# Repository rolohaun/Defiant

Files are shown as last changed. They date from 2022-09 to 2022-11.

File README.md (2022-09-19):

# Defiant
 CroXY 3D Printer called Defiant
 
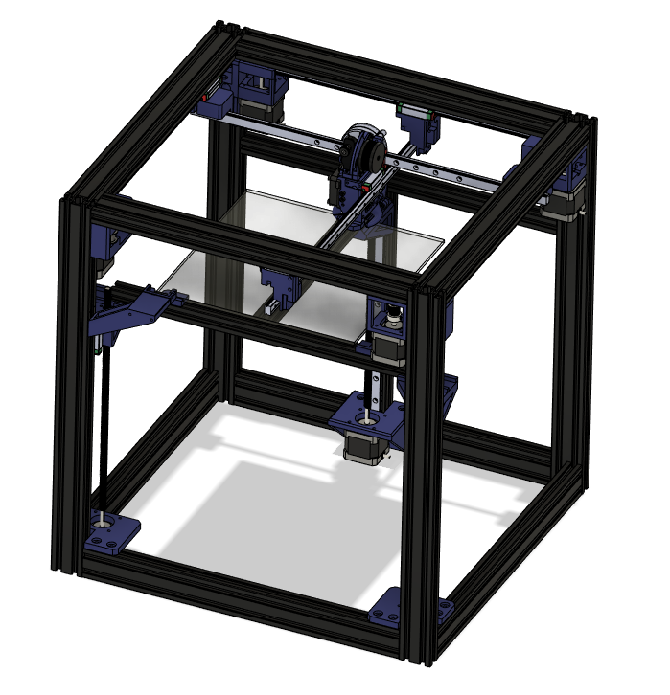
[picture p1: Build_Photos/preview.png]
 
 
 BETA Release
 This printer is a work in progress!! This printer is not enclosable in it's current form
 
 Specs:
 - 2040 Frame
 - 250 x 250 x 250 Printable Area
 - Klicky Probe Support
 - 3 Point Z tilt with independant Z motors
 
 BOM for Belted Z ( Work in Progress )  
 https://docs.google.com/spreadsheets/d/1MMBtSAIVklJtp9cDsU00cnw-aWT4j8f6p9V2ZHv14fQ/edit?usp=sharing
 
 BOM for Lead Screw Z ( Work in Progress )  
 https://docs.google.com/spreadsheets/d/1SVTLotEsgObyTigMcOwIdOpesXPSQrzdjuApPx5pESk/edit?usp=sharing
 
 Support me on Patreon  
 https://www.patreon.com/rolohaun
 
 Find it on YouTube

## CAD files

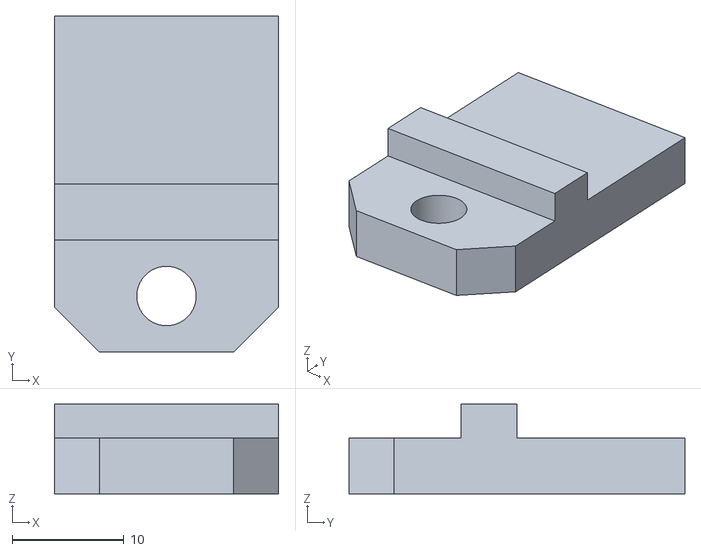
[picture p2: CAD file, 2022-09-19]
Bed/1 x Glass_Bed_Mount Rear.stl
20.0 x 30.0 x 8.00

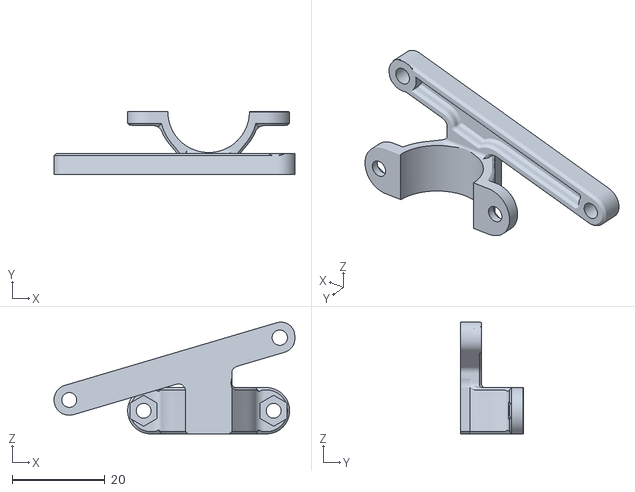
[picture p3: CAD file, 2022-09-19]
Cooling/Clamp_2.stl
52.1 x 13.5 x 24.2

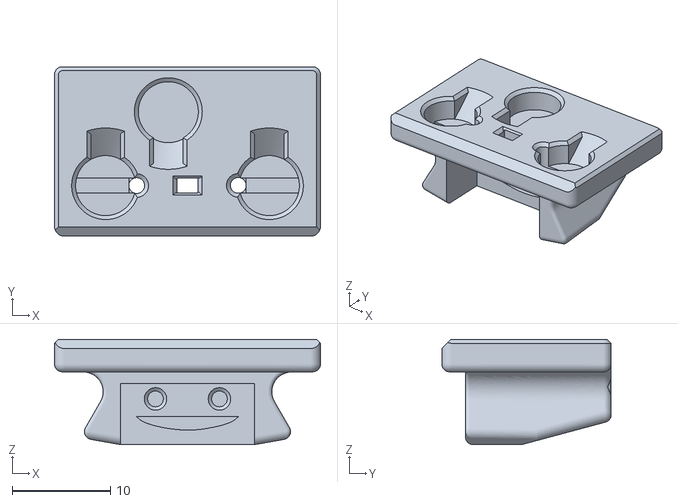
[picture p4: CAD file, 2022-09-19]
Klicky/Klicky_Probe.stl
27.0 x 17.2 x 10.7

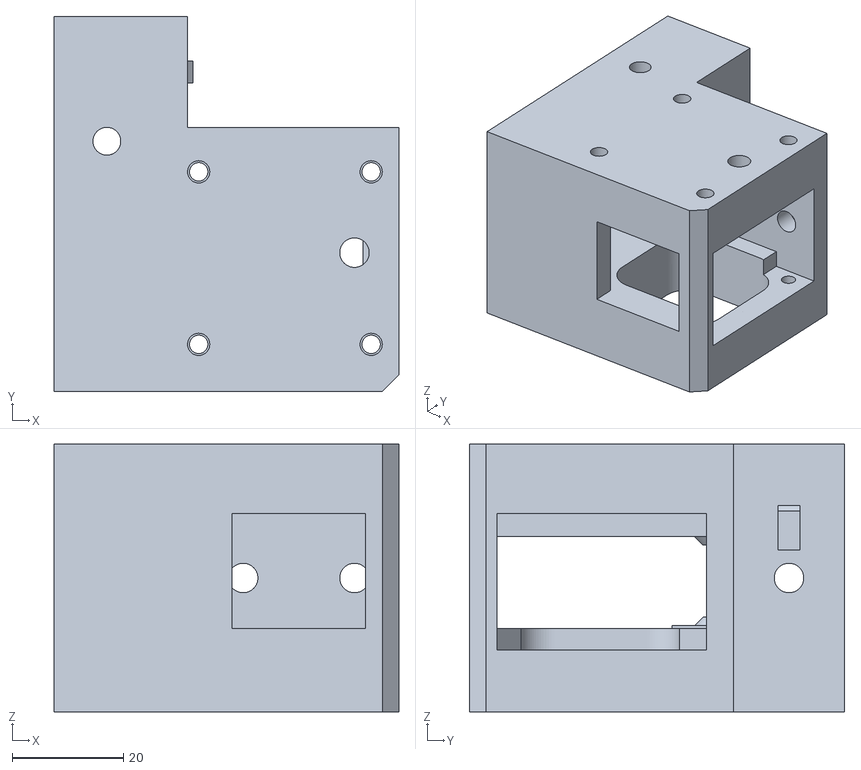
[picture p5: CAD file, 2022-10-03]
Motor Pods/Rear_Right_and_Front_Left_Motor_Pod.stl
62.0 x 67.4 x 48.1

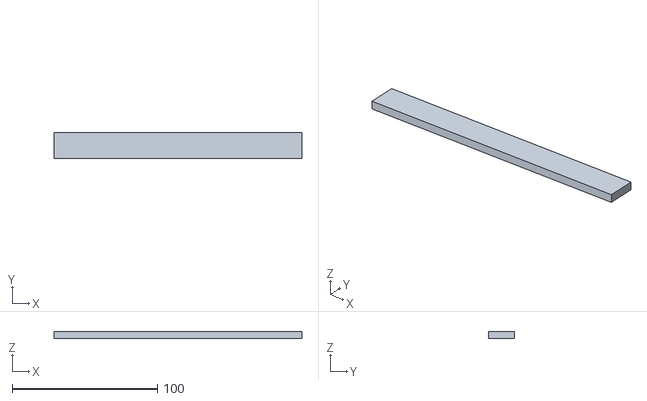
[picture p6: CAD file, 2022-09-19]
Rear_2020_Aligment_Tool.stl
171.0 x 18.0 x 5.00

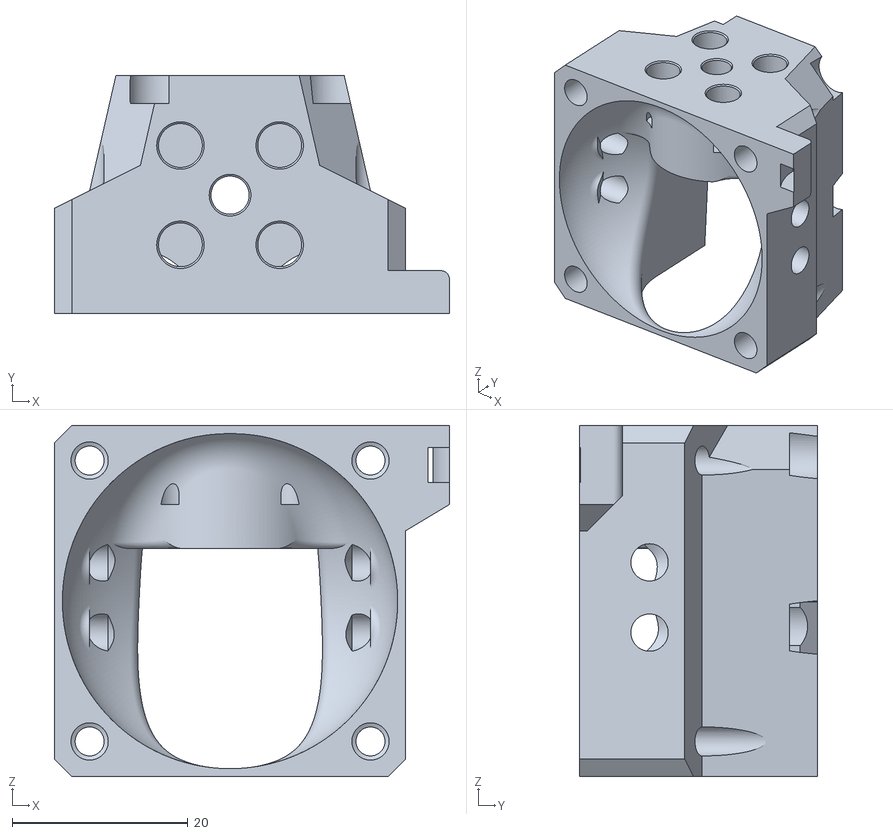
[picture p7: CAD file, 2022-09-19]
Toolhead/EVA3_Modded_Rapido_Mount.stl
45.0 x 27.2 x 40.0

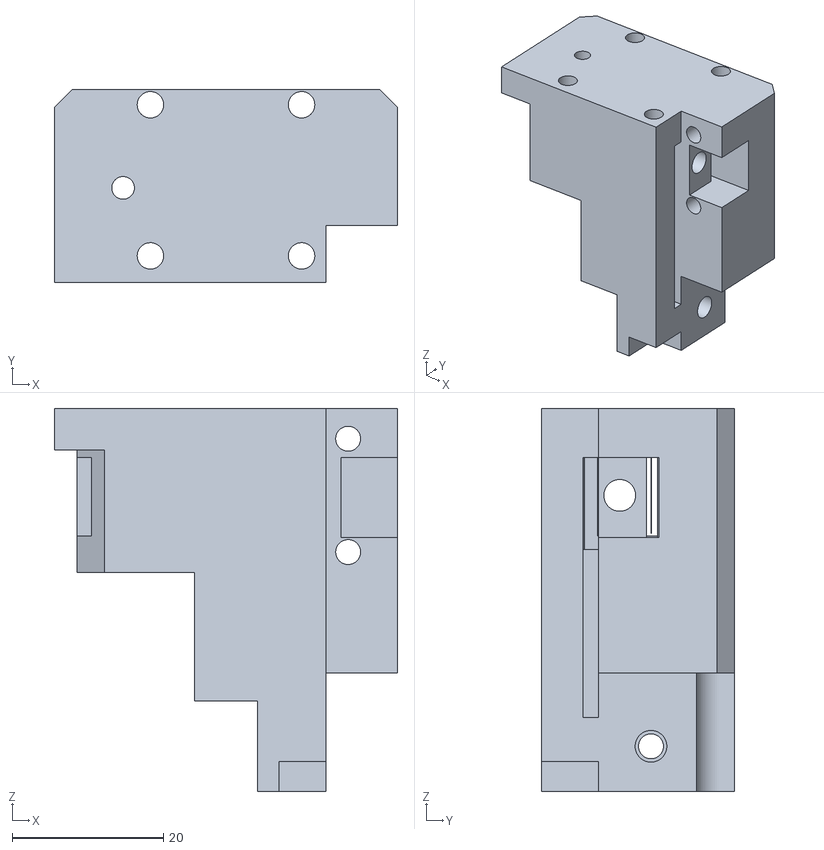
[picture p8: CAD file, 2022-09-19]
X/Rear_X_Rail_Carriage_New.stl
45.4 x 25.5 x 50.7

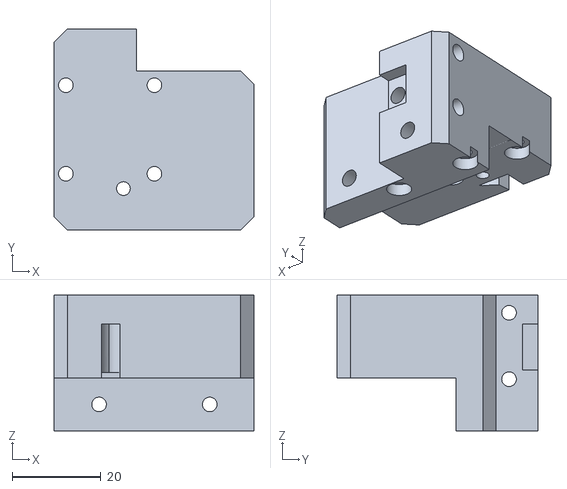
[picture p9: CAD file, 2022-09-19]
Y/Left_Y_Rail_Carriage.stl
45.2 x 45.4 x 30.7

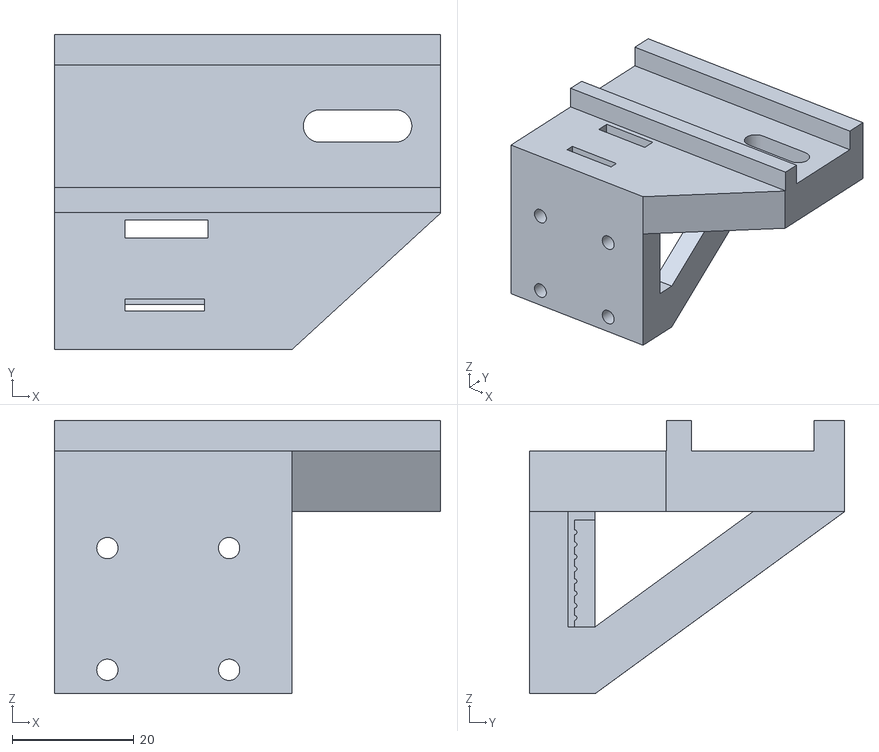
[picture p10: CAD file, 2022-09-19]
Z Belted Version/1 X Left_Belted_Z_Bed_Mount.stl
63.4 x 51.8 x 44.9

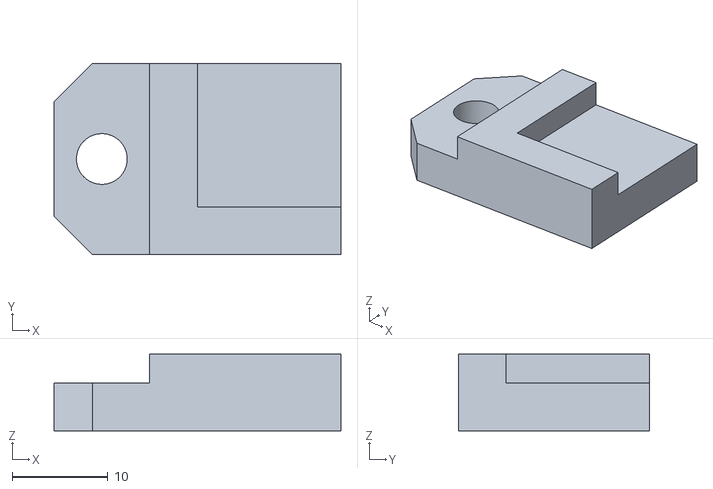
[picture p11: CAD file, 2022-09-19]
Bed/1 x Glass_Bed_Mount_Left.stl
30.0 x 20.0 x 8.00

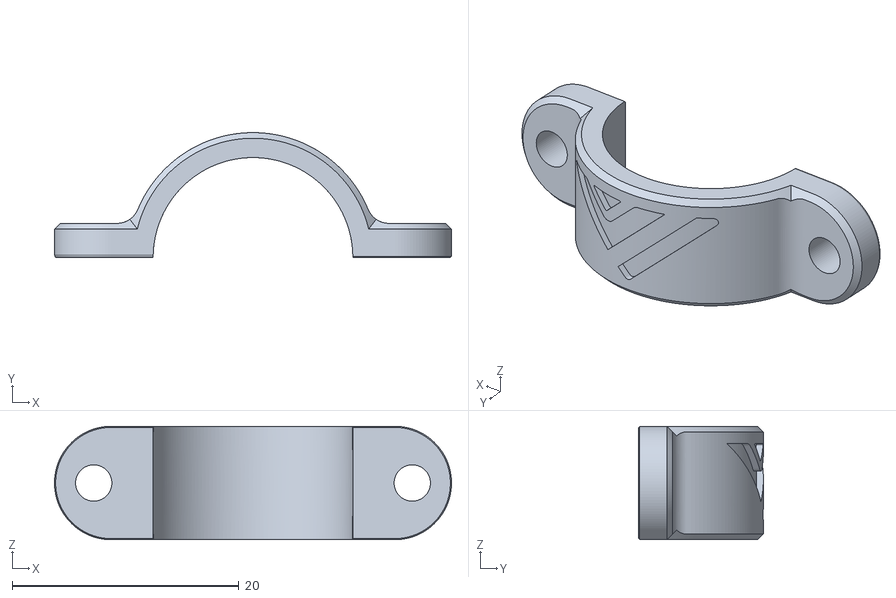
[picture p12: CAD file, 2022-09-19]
Cooling/Clamp_1.stl
35.0 x 11.0 x 10.0

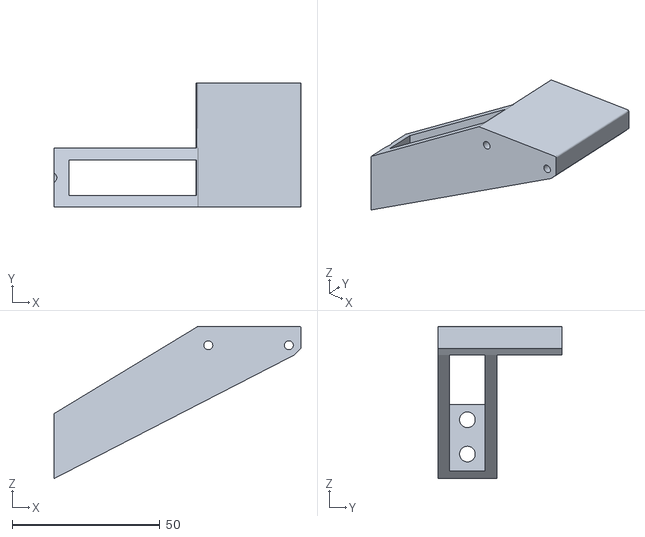
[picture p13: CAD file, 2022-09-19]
Klicky/Klicky_Frame_Mount.stl
83.6 x 42.1 x 51.5

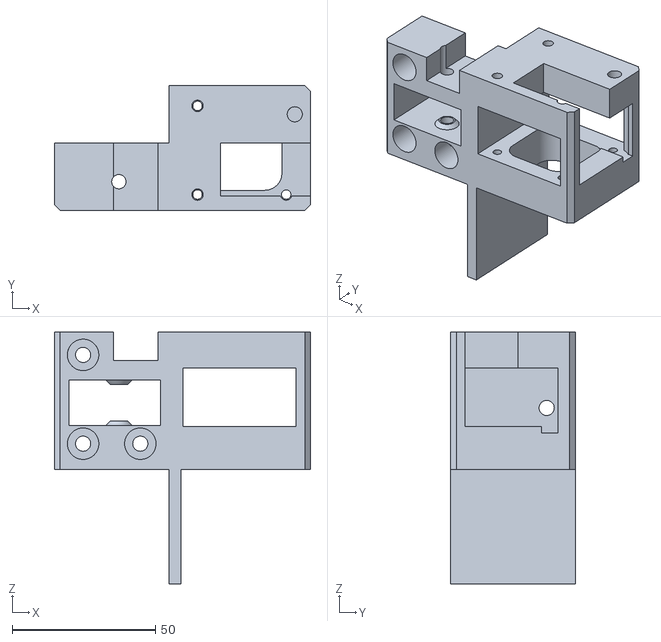
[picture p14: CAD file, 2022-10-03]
Motor Pods/Left_Rear_and_Front_Right_Motor_Pod.stl
89.5 x 43.6 x 88.1

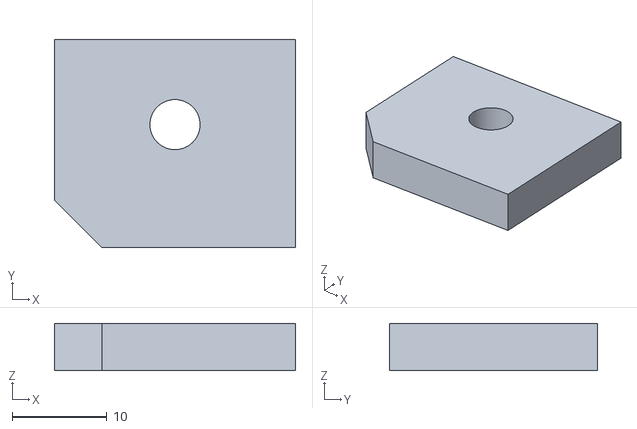
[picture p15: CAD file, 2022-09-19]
Right_Touch_Plate.stl
25.5 x 22.0 x 5.00

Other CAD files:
Toolhead/EVA3_Modded.stl
X/Front_X_Rail_Carriage_New.stl
Y/Right_Y_Rail_Carriage.stl
Z Belted Version/1 X Right_Belted_Z_Bed_Mount.stl
4 X Belt_Clamp.stl
4 X Belt_Slide.stl
Bed/1 x Glass_Bed_Mount Right.stl
Cooling/Duct_Adapter.stl
Klicky/Klicky_Probe_Dock.stl
Rear_Touch_Plate.stl
Z Belted Version/1 X Left_Belted_Z_Idler_Mount.stl
Z Belted Version/1 X Left_Belted_Z_Motor_Mount.stl
Z Belted Version/1 X Rear_Belted_Z_Bed_Mount.stl
Z Belted Version/1 X Rear_Belted_Z_Idler_Mount.stl
Z Belted Version/1 X Rear_Belted_Z_Motor_Mount.stl
Z Belted Version/1 X Right_Belted_Z_Idler_Mount.stl
Z Belted Version/1 X Right_Belted_Z_Motor_Mount.stl
Z Lead Scew Version/1 X Front_Left_Lead_Screw_Z_ Motor_Mount.stl
Z Lead Scew Version/1 X Front_Left_Lead_Screw_Z_2020_Bed_Mount.stl
Z Lead Scew Version/1 X Front_Right_Lead_Screw_Z_ Motor_Mount.stl
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

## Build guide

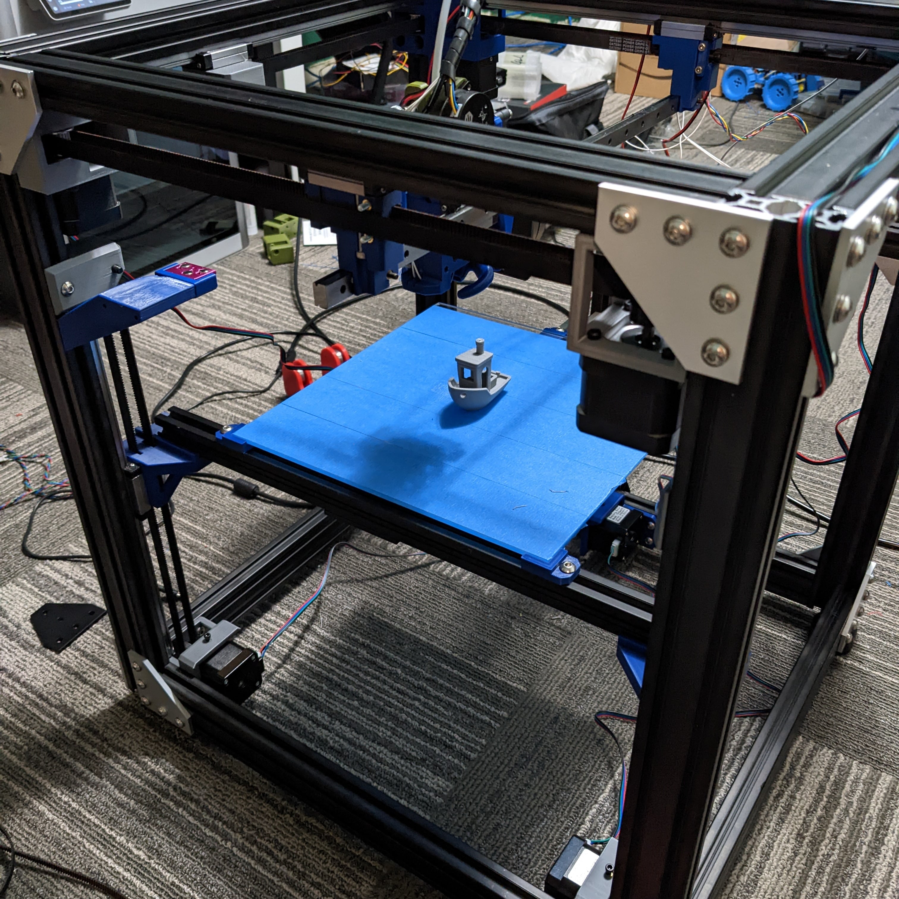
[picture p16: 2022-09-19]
Build_Photos/IMG_20220912_205525_022.jpg

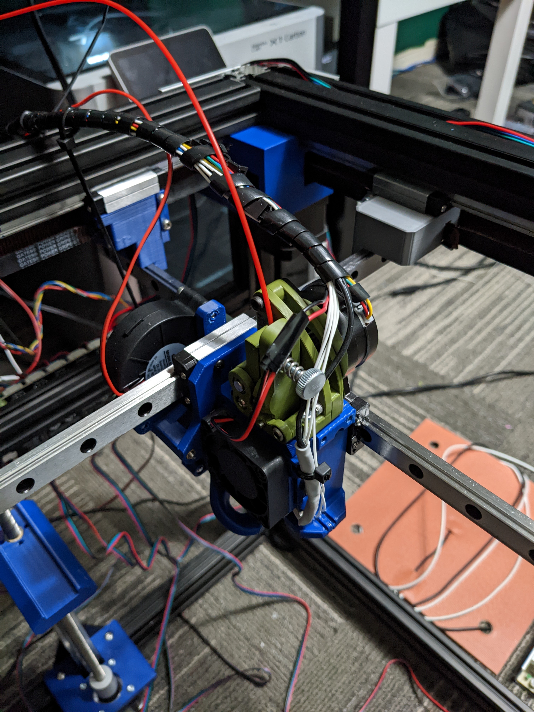
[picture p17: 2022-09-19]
Build_Photos/PXL_20220919_134602779.jpg

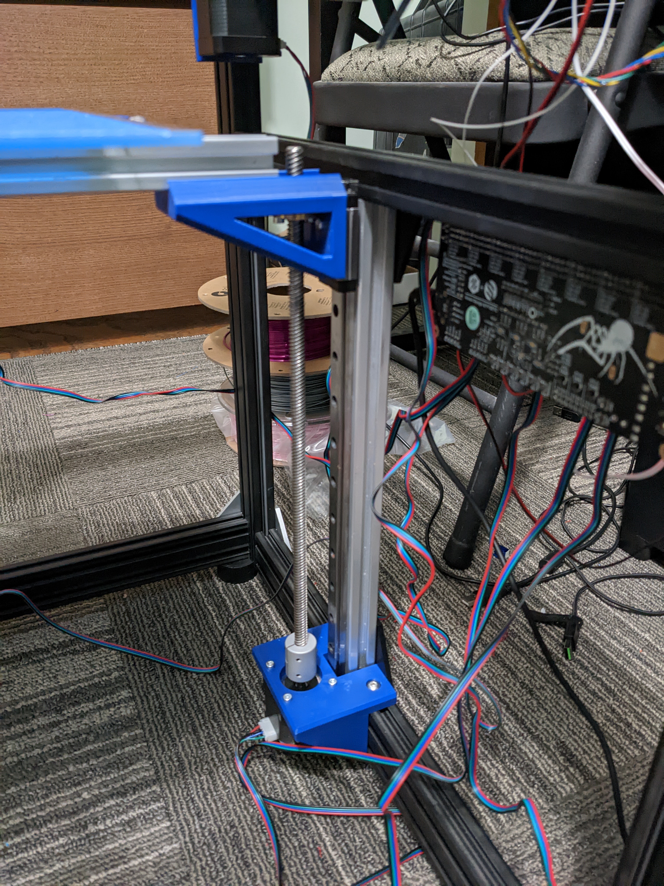
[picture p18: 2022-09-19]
Build_Photos/PXL_20220919_045848959.jpg

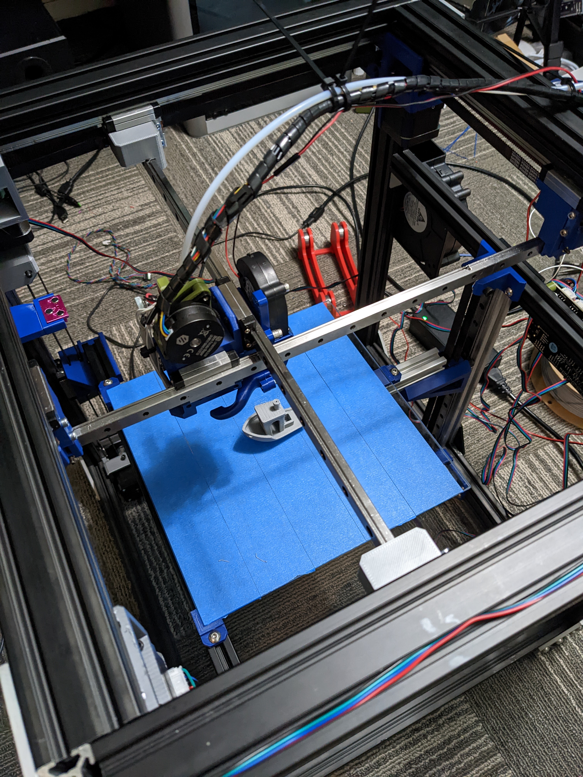
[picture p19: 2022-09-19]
Build_Photos/PXL_20220913_025437549.jpg

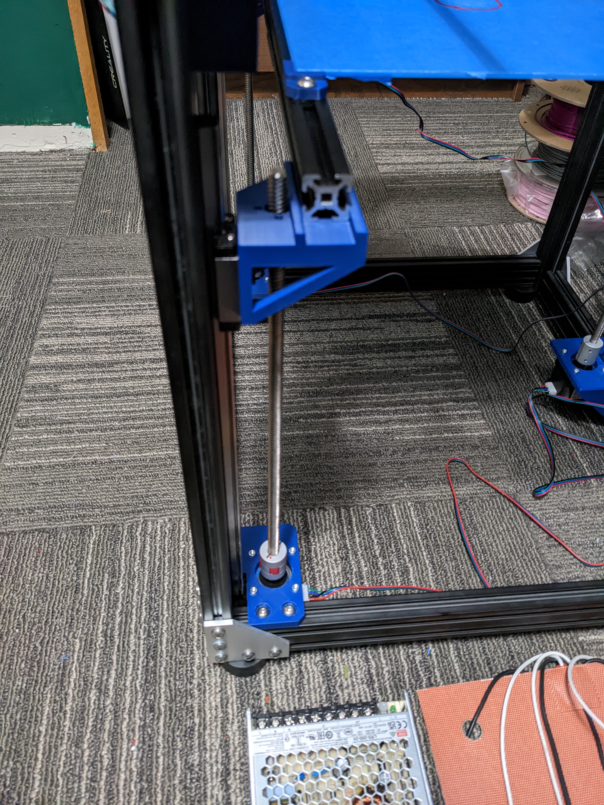
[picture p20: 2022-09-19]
Build_Photos/PXL_20220919_045845205.jpg

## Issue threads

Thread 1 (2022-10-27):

What material to print the 3d parts?

johnnytshi, 2022-10-27:
What material do you recommend to print the 3d parts? ABS, PC...

Preferably something I can get on Amazon Canada

Cheers!

rolohaun, 2022-10-27:
Polymaker ASA or ABS, PETG if you can print those other ones

On Wed, Oct 26, 2022 at 9:45 PM Johnny Ting Shi ***@***.***>
wrote:

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

Closed 2023-07-03.

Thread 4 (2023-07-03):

What speeds and feeds?

PerLangkjaer, 2023-07-03:
I am on the way to design a cross-gantry printer, but with the Ultimaker rod style design, when I stumbled across this :-D
Instead of me starting all over, I maybe should build this?
What are you looking at for speeds and feeds when printing with this?

Personnally I like the RatRig Z-axis assembly and the 30x30 extrusions...

rolohaun, 2023-07-03:
been a while since I used mine but it was printing 16 minute benchies pretty easily. was 10 - 15k accel and 200mm/s

PerLangkjaer, 2023-07-03:
Thanks
I'll look into it a bit more, and I might build one soon...
BTW love your work ;-)

PerLangkjaer, 2023-07-03:
I'm not that active on Discord, but would like to discuss some design ideas, so might take that up ;-)

Closed 2023-07-03.

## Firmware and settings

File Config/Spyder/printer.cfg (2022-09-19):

[include mainsail.cfg]
[include klicky-probe.cfg]
[include macros.cfg]
#[include adxl.cfg]

# Stepper Configs
[stepper_x]
# connected to X Stepper on SPIDER
step_pin: PE11
dir_pin: !PE10
enable_pin: !PE9
rotation_distance: 40
microsteps: 64
endstop_pin: tmc2209_stepper_x:virtual_endstop 
position_endstop: 250
position_max: 250
homing_speed: 50
homing_retract_dist: 0

[tmc2209 stepper_x]
# connected to X Stepper on SPIDER
uart_pin: PE7
run_current: .7
sense_resistor: 0.110
stealthchop_threshold: 0
interpolate: False
diag_pin: PB14
driver_SGTHRS: 70



[stepper_x1]
# connected to Y Stepper on SPIDER
step_pin: PD8
dir_pin: PB12
enable_pin: !PD9
rotation_distance: 40
microsteps: 64
endstop_pin: tmc2209_stepper_x1:virtual_endstop 

[tmc2209 stepper_x1]
# connected to Y Stepper on SPIDER
uart_pin: PE15
run_current: .7
sense_resistor: 0.110
stealthchop_threshold: 0
interpolate: False
diag_pin: PB13 
driver_SGTHRS: 70



[stepper_y]
# connected to Z Stepper on SPIDER
step_pin: PD14
dir_pin: !PD13
enable_pin: !PD15
rotation_distance: 40
microsteps: 64
endstop_pin: tmc2209_stepper_y:virtual_endstop 
position_endstop: 240
position_max: 240
homing_speed: 50
homing_retract_dist: 0

[tmc2209 stepper_y]
# connected to Z Stepper on SPIDER
uart_pin: PD10
run_current: .7
sense_resistor: 0.110
stealthchop_threshold: 0
interpolate: False
diag_pin: PA0
driver_SGTHRS: 70


[stepper_y1]
# connected to E0 Stepper on SPIDER
step_pin: PD5
dir_pin: !PD6
enable_pin: !PD4
rotation_distance: 40
microsteps: 64
endstop_pin: tmc2209_stepper_y1:virtual_endstop 

[tmc2209 stepper_y1]
# connected to E0 Stepper on SPIDER
uart_pin: PD7
run_current: .7
sense_resistor: 0.110
stealthchop_threshold: 0
interpolate: False
diag_pin: PA3
driver_SGTHRS: 70


#------------------------------------------------------------------------------------
[stepper_z]
# connected to E1 Stepper on SPIDER
step_pin: PE6
dir_pin: !PC13
enable_pin: !PE5
rotation_distance: 8
microsteps: 64
endstop_pin: probe:z_virtual_endstop
position_max: 275
position_min: -5
homing_speed: 15.0
second_homing_speed: 5.0
homing_retract_dist: 10.0

[tmc2209 stepper_z]
# connected to E1 Stepper on SPIDER
uart_pin: PC14
run_current: .5 
sense_resistor: 0.110
stealthchop_threshold: 0
interpolate: False

 #--------------------------------------------------------------------------------
[stepper_z1]
# connected to E2 Stepper on SPIDER
step_pin: PE2
dir_pin: !PE4
enable_pin: !PE3
rotation_distance: 8
microsteps: 64

[tmc2209 stepper_z1]
# connected to E2 Stepper on SPIDER
uart_pin: PC15
run_current: .5
sense_resistor: 0.110
stealthchop_threshold: 0
interpolate: False

 #--------------------------------------------------------------------------------
[stepper_z2]
# connected to E3 Stepper on SPIDER
step_pin: PD12
dir_pin: !PC4
enable_pin: !PE8
rotation_distance: 8
microsteps: 64

[tmc2209 stepper_z2]
# connected to E3 Stepper on SPIDER
uart_pin: PA15
run_current: .5
sense_resistor: 0.110
stealthchop_threshold: 0
interpolate: False
#---------------------------------------------------------------------------------


# Extruder0
[extruder]
# connected to E4 Stepper on SPIDER
step_pin: PE1
dir_pin: PE0
enable_pin: !PC5
rotation_distance: 22.67895 #for 5mm Shaft Driven Bondtech gearsets
gear_ratio: 50:10 #for standard 10t motor
microsteps: 64
nozzle_diameter: 0.400
pressure_advance: 0.035
pressure_advance_smooth_time: 0.040
filament_diameter: 1.750	
# connected to Thermistor0 on SPIDER
sensor_type: ATC Semitec 104NT-4-R025H42G
sensor_pin: PC0
min_extrude_temp: 0
min_temp: 0
max_temp: 300
heater_pin: PB15
max_power: 1.0
max_extrude_only_distance: 1400.0
max_extrude_only_velocity: 120.0
max_extrude_only_accel: 1500.0
max_extrude_cross_section: 20000.0

[tmc2209 extruder]
# connected to E4 Stepper on SPIDER
uart_pin: PD11
run_current: 0.2
sense_resistor: 0.110
stealthchop_threshold: 0
interpolate: False
# connected to Heater0 on SPIDER


# Fans  
# Hotend Cooling Fan
[heater_fan my_nozzle_fan]
# connected to Fan0 on SPIDER - 12v Fan
pin: PA13
max_power: 1.0
#kick_start_time: 0.5
heater: extruder
heater_temp: 50.0
 
# print cooling fan
[fan]
# connected to Fan1 on SPIDER - 12v Fan
pin: PA14 #PC8
max_power: 1.0
kick_start_time: 0.500

[probe]
##	If your probe is NO instead of NC, change pin to ^!PA3
pin: ^PA1
x_offset: 0
y_offset: -19
z_offset: 1.4
speed: 5
samples: 2
samples_result: median
sample_retract_dist: 3.0
samples_tolerance: 0.05
samples_tolerance_retries: 3

[z_tilt]
horizontal_move_z: 10
##200mm build
z_positions:
    15, 0
    165, 400
    315, 0
points:
    30, 35
    130, 235
    250, 35
speed: 200
horizontal_move_z: 10
retries: 5
retry_tolerance: 0.015

#[safe_z_home]
#home_xy_position: 125, 120 # Change coordinates to the center of your print bed
#speed: 40
#z_hop: 0                 # Move up 10mm
#z_hop_speed: 5

# Mesh Bed Settings
[bed_mesh]
speed: 200
horizontal_move_z: 20.0
mesh_min: 20,25
mesh_max: 150, 155
probe_count: 5,5
fade_start: 0.5
fade_end: 2
split_delta_z: .025
move_check_distance: 5.0
mesh_pps: 2,2
algorithm: bicubic
bicubic_tension: 0.1
relative_reference_index: 12  # ^^^because were measuring the offset from the nozzle switch to the bed using the center of the bed, the equation to find the location = (probe point count)/2-1


# MCU SPIDER
[mcu] 
serial: /dev/serial/by-id/usb-Klipper_stm32f446xx_2D0030001951303439363932-if00
restart_method: command

# EXP1 / EXP2 (display) pins
[board_pins]
aliases:
    # EXP1 header
    EXP1_1=PC9, EXP1_2=PA8,
    EXP1_3=PC11, EXP1_4=PD2,
    EXP1_5=PC10, EXP1_6=PC12,    # Slot in the socket on this side
    EXP1_7=PD0, EXP1_8=PD1,
    EXP1_9=<GND>, EXP1_10=<5V>,

    # EXP2 header
    EXP2_1=PA6, EXP2_2=PA5,
    EXP2_3=PC6, EXP2_4=PA4,
    EXP2_5=PC7, EXP2_6=PA7,      # Slot in the socket on this side
    EXP2_7=PB10, EXP2_8=<RST>,
    EXP2_9=<GND>, EXP2_10=<5V>


#virtual sdcard settings
[virtual_sdcard]
path: ~/gcode_files

#enable display status for moonraker
[display_status]

# Enable Pause/Resume Functionality
[pause_resume]

#Gcode G2/G3 Arc Support
[gcode_arcs]
resolution: 0.1

#Printer Speeds and Accels
[printer]
kinematics: cartesian
max_velocity: 500
max_accel: 10000 # change this to 7500 after commissioning
max_z_velocity: 15   # may be able to increase to 15 after comissioning.
max_z_accel: 50
square_corner_velocity: 4 # start at 8, but then increase once you're sure assembly is sound


# Motor and Heater Idle Timeout
[idle_timeout]
timeout: 6000

#*# <---------------------- SAVE_CONFIG ---------------------->
#*# DO NOT EDIT THIS BLOCK OR BELOW. The contents are auto-generated.
#*#
#*# [extruder]
#*# control = pid
#*# pid_kp = 21.086
#*# pid_ki = 1.673
#*# pid_kd = 66.420
#*#
#*# [input_shaper]
#*# shaper_type_x = zv
#*# shaper_freq_x = 58.0
#*# shaper_type_y = zv
#*# shaper_freq_y = 55.8

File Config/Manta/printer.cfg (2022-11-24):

# STM32G0B1, "8KiB bootloader", USB communication

[include mainsail.cfg]
[include klicky-probe.cfg]
[include macros.cfg]

# Beware the mooove
[force_move]
enable_force_move: True

[stepper_x]
# connected to M1 stepper on manta
step_pin: PE2
dir_pin: !PB4
enable_pin: !PC11
rotation_distance: 40
microsteps: 64
endstop_pin: tmc2209_stepper_x:virtual_endstop 
position_endstop: 250
position_max: 250
homing_speed: 50
homing_retract_dist: 0

[tmc2209 stepper_x]
# connected to M1 Stepper on manta
uart_pin: PC10
run_current: .7
sense_resistor: 0.110
stealthchop_threshold: 0
interpolate: False
diag_pin: PF3
driver_SGTHRS: 70

[stepper_x1]
# connected to M2 Stepper on manta
step_pin: PF12
dir_pin: PF11
enable_pin: !PB3
rotation_distance: 40
microsteps: 64
endstop_pin: tmc2209_stepper_x1:virtual_endstop 

[tmc2209 stepper_x1]
# connected to M2 Stepper on manta
uart_pin: PF13
run_current: .7
sense_resistor: 0.110
stealthchop_threshold: 0
interpolate: False
diag_pin: PF4
driver_SGTHRS: 70

[stepper_y]
# connected to M3 Stepper on manta
step_pin: PD7
dir_pin: PD6
enable_pin: !PF10
rotation_distance: 40
microsteps: 64
endstop_pin: tmc2209_stepper_y:virtual_endstop 
position_endstop: 240
position_max: 240
homing_speed: 50
homing_retract_dist: 0

[tmc2209 stepper_y]
# connected to M3 Stepper on manta
uart_pin: PF9
run_current: .7
sense_resistor: 0.110
stealthchop_threshold: 0
interpolate: False
diag_pin: PF5
driver_SGTHRS: 65

[stepper_y1]
# connected to M4 Stepper on manta
step_pin: PD3
dir_pin: !PD2
enable_pin: !PD5
rotation_distance: 40
microsteps: 64
endstop_pin: tmc2209_stepper_y1:virtual_endstop 

[tmc2209 stepper_y1]
# connected to M4 Stepper on manta
uart_pin: PD4
run_current: .7
sense_resistor: 0.110
stealthchop_threshold: 0
interpolate: False
diag_pin: PC0
driver_SGTHRS: 65

# TODO: put these in reading order
# This config is built around z motors being ordered as follows. From the front: z1 z z2.
[stepper_z]
# connected to M5 Stepper on manta
step_pin: PC9
dir_pin: PC8
enable_pin: !PD1
rotation_distance: 8
microsteps: 64
endstop_pin: probe:z_virtual_endstop
position_max: 275
position_min: -5
homing_speed: 15.0
second_homing_speed: 5.0
homing_retract_dist: 10.0

[tmc2209 stepper_z]
# connected to M5 Stepper on manta
uart_pin: PD0
run_current: .5 
sense_resistor: 0.110
stealthchop_threshold: 0
interpolate: False

[stepper_z1]
# connected to M6 Stepper on manta
step_pin: PA10
dir_pin: PD15
enable_pin: !PA15
rotation_distance: 8
microsteps: 64

[tmc2209 stepper_z1]
# connected to M6 Stepper on manta
uart_pin: PF8
run_current: .5
sense_resistor: 0.110
stealthchop_threshold: 0
interpolate: False

[stepper_z2]
# connected to M7 Stepper on manta
step_pin: PD12
dir_pin: PD11
enable_pin: !PD14
rotation_distance: 8
microsteps: 64

[tmc2209 stepper_z2]
# connected to M7 Stepper on manta
uart_pin: PD13
run_current: .5
sense_resistor: 0.110
stealthchop_threshold: 0
interpolate: False

[extruder]
step_pin: PD10
dir_pin: !PD8
enable_pin: !PD9
#rotation_distance: 22.67895 #for 5mm Shaft Driven Bondtech gearsets
rotation_distance: 22.22537
gear_ratio: 50:10 #for standard 10t motor
microsteps: 64
nozzle_diameter: 0.400
pressure_advance: 0.035
pressure_advance_smooth_time: 0.040
filament_diameter: 1.750	
#sensor_type: Generic 3950
sensor_type: ATC Semitec 104NT-4-R025H42G
sensor_pin: PA1 #T0
min_extrude_temp: 0
control: pid
pid_Kp: 30.224
pid_Ki: 3.535
pid_Kd: 64.605
min_temp: 0
max_temp: 300
heater_pin: PE3 #HE0
max_power: 1.0
max_extrude_only_distance: 1400.0
max_extrude_only_velocity: 120.0
max_extrude_only_accel: 1500.0
max_extrude_cross_section: 20000.0

[heater_fan nozzle_fan]
# connected to Fan0 on manta
pin: PE6
max_power: 1.0
heater: extruder
heater_temp: 50.0

[tmc2209 extruder]
# connected to M8 Stepper on manta
uart_pin: PC7
run_current: 0.2
sense_resistor: 0.110
stealthchop_threshold: 0
interpolate: False

[heater_bed]
heater_pin: PB5 #HE1
sensor_pin: PA0 # TB
sensor_type: Generic 3950
control = pid
pid_Kp=40.671
pid_Ki=0.832
pid_Kd=497.206
min_temp: 0
max_temp: 130

[bed_screws]
screw1: 240, 0
screw2: 145, 240
screw3: 0, 0

[fan]
pin: PE0
max_power: 1.0
kick_start_time: 0.500

[mcu]
serial: /dev/serial/by-id/usb-Klipper_stm32g0b1xx_m8p-if00

#enable display status for moonraker
[display_status]

# Enable Pause/Resume Functionality
[pause_resume]

#Gcode G2/G3 Arc Support
[gcode_arcs]
resolution: 0.1

#Printer Speeds and Accels
[printer]
kinematics: cartesian
max_velocity: 500
max_accel: 10000
max_z_velocity: 15
max_z_accel: 50
square_corner_velocity: 4

# Motor and Heater Idle Timeout
[idle_timeout]
timeout: 6000

[board_pins]
aliases:
    # EXP1 header
    EXP1_1=PE9, EXP1_2=PE10,
    EXP1_3=PE11, EXP1_4=PE12,
    EXP1_5=PE13, EXP1_6=PE14,    # Slot in the socket on this side
    EXP1_7=PE15, EXP1_8=PB10,
    EXP1_9=<GND>, EXP1_10=<5V>,

    # EXP2 header
    EXP2_1=PB14, EXP2_2=PB13,
    EXP2_3=PF7, EXP2_4=PB12,
    EXP2_5=PE7, EXP2_6=PB11,      # Slot in the socket on this side
    EXP2_7=PE8, EXP2_8=<RST>,
    EXP2_9=<GND>, EXP2_10=PC5

# See the sample-lcd.cfg file for definitions of common LCD displays.


# Probe is plugged in to M6-STOP on the manta. Be warned all endstop pins can share with DIAG.
[probe]
pin: ^PC2
x_offset: 0
y_offset: -19
z_offset: 1.760

# Klicky has you comment this
#[safe_z_home]
#home_xy_position: 125, 120
#speed: 40
#z_hop: 10
#z_hop_speed: 15

[z_tilt]
horizontal_move_z: 10
z_positions:
    165, 235
    15, 5
    235, 5
points:
    15, 35
# TODO: get z motors in reading order
#    125, 240
    150, 240
    235, 35
speed: 200
horizontal_move_z: 10
retries: 5
retry_tolerance: 0.015

[bed_mesh]
speed: 200
mesh_min: 20,20
mesh_max: 230, 220
probe_count: 5,5

## <---------------------- SAVE_CONFIG ---------------------->
## DO NOT EDIT THIS BLOCK OR BELOW. The contents are auto-generated.
##

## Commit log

2022-11-24 Minor re-org. Add Klipper configuration for the BTT Manta M8P.
    [adxl.cfg, klicky-bed-mesh-calibrate.cfg, klicky-macros.cfg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]
2022-11-24 Move Spyder config to match.
    [printer.cfg]
2022-11-24 Comment on z motor weirdness
    [printer.cfg]
